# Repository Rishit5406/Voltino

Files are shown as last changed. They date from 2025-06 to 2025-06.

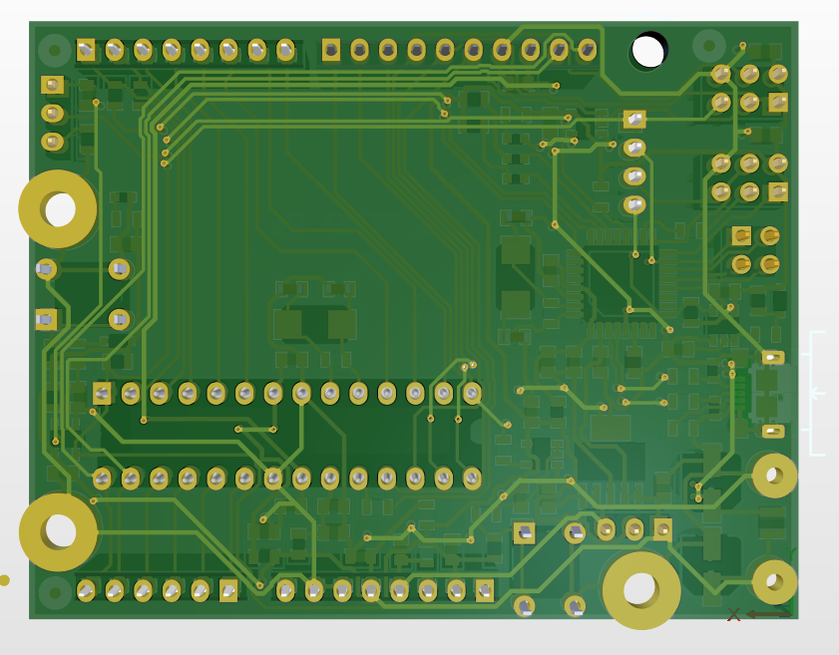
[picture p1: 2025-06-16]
6. Images of PCB/Bottom View.png

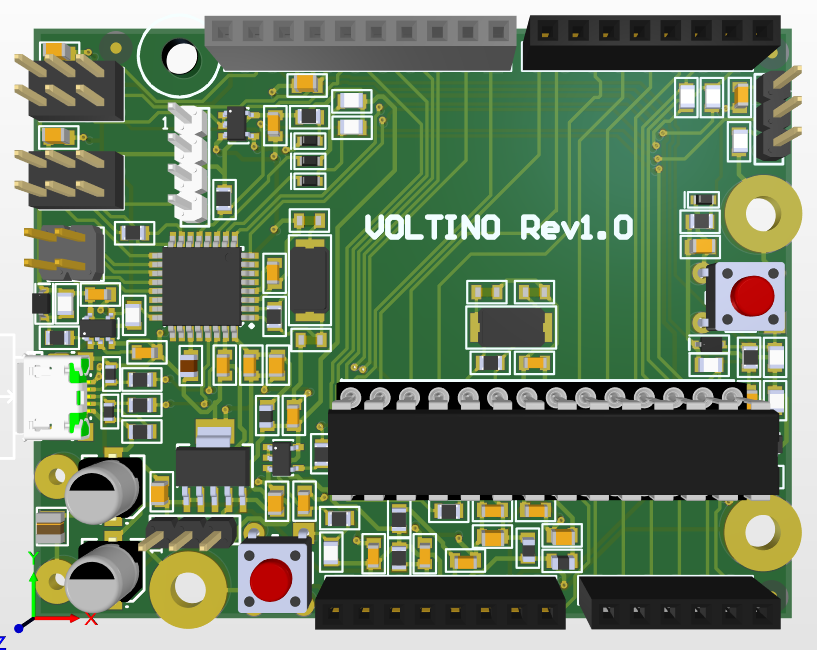
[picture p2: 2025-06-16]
6. Images of PCB/Top View.png

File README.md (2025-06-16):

# VOLTINO – Arduino UNO Rev 3 Inspired Custom Board

**VOLTINO** is a custom-designed, open-source hardware development board inspired by the Arduino™ UNO Rev 3. This project refines the original design based on **Atmel's electrical recommendations** for better current and voltage control, optimized trace routing, and mechanical reliability.

Designed in **Altium Designer**, VOLTINO preserves the standard Arduino UNO pinout while offering a clean layout and professional fabrication-ready output.

---

## 🔧 Features
- Based on **ATmega328P-PU**
- UNO R3 compatible pin headers
- USB and external power supply support
- Enhanced voltage and current control
- Designed for manufacturability and reliability
- STEP file provided for enclosure/CAD integration

---

## 📁 Repository Contents

### 1. `Schematic/`
- Altium schematic PDF of the complete design
- Includes pin labels, power supply routing, and interface mappings

### 2. `PCB Layout/`
- PCB layout PDF exported from Altium
- Layer stack, footprint arrangement, trace routing overview

### 3. `BOM/`
- Bill of Materials (CSV or XLSX)
- Includes part numbers, footprints, and quantity for sourcing

### 4. `STEP File/`
- 3D mechanical export of the PCB in `.STEP` format
- Can be used in Fusion 360, SolidWorks, FreeCAD, etc.

### 5. `Gerber Files/`
- Complete set of fabrication-ready Gerber and NC drill files
- Compliant with JLCPCB, PCBWay, OSH Park, and most fab services

### 6. `Images/`
- High-resolution images:
  - 3D PCB view
  - Annotated schematic
  - Component layout and connections

---

## 🚀 Getting Started

This repository is intended for:
- Makers and hardware engineers looking for an optimized UNO design
- Students building embedded projects
- Fabricators needing ready-to-manufacture open-source boards

To manufacture VOLTINO:
1. Download the Gerber ZIP
2. Upload to your preferred PCB fabricator (e.g., JLCPCB)
3. Refer to the BOM for sourcing components
4. Use the STEP file for enclosure design or 3D simulation

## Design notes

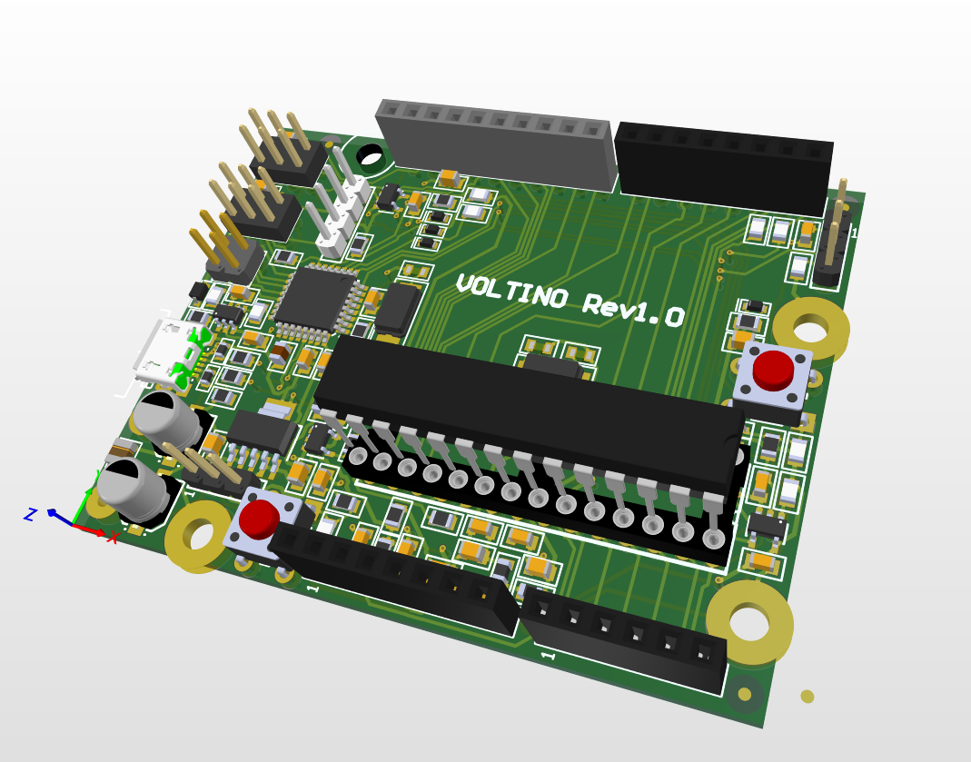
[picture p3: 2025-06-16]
6. Images of PCB/Side View 1.png

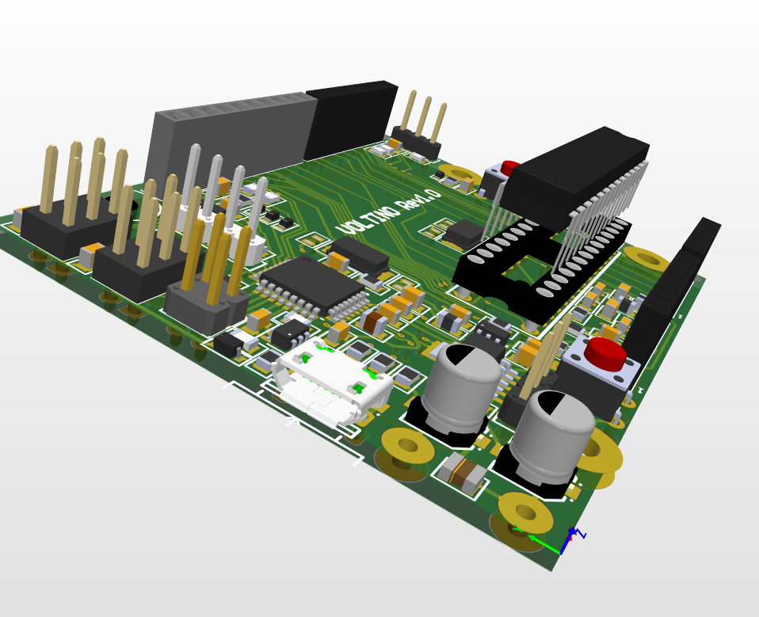
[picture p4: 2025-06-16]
6. Images of PCB/Side View 2.png

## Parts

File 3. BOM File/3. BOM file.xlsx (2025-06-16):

Description | LibRef | Category | Supplier | Supplier Part Number | Manufacturer | Manufacturer Part Number | Quantity | Pricing
Ceramic Capacitor, Multilayer, Ceramic, 50V, 10% +Tol, 10% -Tol, X7R, 15% TC, 0.1uF, Surface Mount, 0805 | C2012X7R1H104K085AA | Ceramic Capacitors | Digikey | 445-7534-1-ND | TDK | C2012X7R1H104K085AA | 17 | 1=0.12, 10=0.069, 100=0.0418, 1000=0.02773 (USD)
Ceramic Capacitor, Multilayer, Ceramic, 16V, 10% +Tol, 10% -Tol, X5R, 15% TC, 10uF, Surface Mount, 0805 | C2012X5R1C106K085AC | Ceramic Capacitors | Digikey | 445-7644-1-ND | TDK | C2012X5R1C106K085AC | 9 | 1=0.21, 10=0.121, 100=0.076, 1000=0.05277 (USD)
Aluminum Electrolytic Capacitor, Polarized, Aluminum (wet), 10V, 20% +Tol, 20% -Tol, 100uF, Surface Mount, 2121 | EEE-1AA101WR | Aluminum Electrolytic Capacitors | Digikey | PCE3867CT-ND | Panasonic | EEE-1AA101WR | 2 | 1=0.36, 10=0.22, 50=0.1606, 100=0.1419, 500=0.10952 (USD)
Ceramic Capacitor, Multilayer, Ceramic, 25V, 10% +Tol, 10% -Tol, X5R, 15% TC, 1uF, Surface Mount, 0805 | C2012X5R1E105K125AA | Ceramic Capacitors | Digikey | 445-1419-1-ND | TDK | C2012X5R1E105K125AA | 1 | 1=0.19, 10=0.106, 100=0.0662, 1000=0.04546 (USD)
Ceramic Capacitor, Multilayer, Ceramic, 50V, 5% +Tol, 5% -Tol, C0G, -/+30ppm/Cel TC, 0.000018uF, Surface Mount, 0805 | C0805C180J5GACTU | Ceramic Capacitors | Digikey | 399-C0805C180J5GACTUCT-ND | KEMET | C0805C180J5GACTU | 4 | 1=0.11, 10=0.06, 100=0.0358, 1000=0.0235 (USD)
LED Uni-Color Yellow 591nm Automotive 2-Pin Chip 0603(1608Metric) T/R | LY L29K-J1K2-26-0-2-R18-Z | LEDs | Digikey | 475-LYL29K-J1K2-26-0-2-R18-ZCT-ND | Osram Opto | LY L29K-J1K2-26-0-2-R18-Z | 3 | 1=0.29, 10=0.195, 100=0.1374, 500=0.111, 1000=0.10226, 2000=0.09482 (USD)
Rectifier Diode, 1 Phase, 1 Element, 0.2A, 30V V(RRM), Silicon | BAT54HT1G | Schottky Diodes | Digikey | BAT54HT1GOSCT-ND | ON Semiconductor / Fairchild | BAT54HT1G | 2 | 1=0.11, 10=0.072, 100=0.0512, 500=0.03702, 1000=0.0324 (USD)
Smartled Green Clear Lc Ali | LGL29K-F2J1-24-0-2-R18-Z | LEDs | Digikey | 475-LGL29K-F2J1-24-0-2-R18-ZCT-ND | Osram | LGL29K-F2J1-24-0-2-R18-Z | 1
Ferrite Chip, 1 Function(s), 2A | MPZ2012S601AT000 | Ferrite Beads and Chips | Digikey | 445-MPZ2012S601AT000CT-ND | TDK | MPZ2012S601AT000 | 3 | 1=0.11, 10=0.075, 25=0.0648, 50=0.0584, 100=0.0522, 250=0.04496, 500=0.03994, 1000=0.0353 (USD)
Fixed Resistor, Metal Glaze/thick Film, 0.125W, 560ohm, 150V, 1% +/-Tol, 100ppm/Cel, Surface Mount, 0805 | RC0805FR-07560RL | Chip SMD Resistors | Digikey | 311-560CRCT-ND | Yageo | RC0805FR-07560RL | 3 | 1=0.1, 10=0.012, 100=0.0112, 1000=0.00714 (USD)
Conn Unshrouded Header HDR 4 POS 2.54mm Solder ST Top Entry Thru-Hole BergStik® Bulk | 67997-204HLF | Headers and Wire Housings | Digikey | 609-3233-ND | Amphenol ICC / FCI | 67997-204HLF | 1 | 1=0.4, 10=0.338, 100=0.2873, 500=0.2564, 1000=0.24415, 5000=0.21793, 10000=0.20753 (USD)
Conn Unshrouded Header HDR 6 POS 2.54mm Solder ST Top Entry Thru-Hole BergStik® Bulk | 67997-106HLF | Headers and Wire Housings | Digikey | 609-3393-ND | Amphenol ICC / FCI | 67997-106HLF | 2 | 1=0.58, 10=0.49, 400=0.37728, 800=0.35925, 1200=0.34911, 5200=0.31479, 10000=0.3006 (USD)
Conn Unshrouded Header HDR 4 POS 2.54mm Solder ST Thru-Hole Bag | 68001-204HLF | Headers and Wire Housings | Digikey | 609-3402-ND | Amphenol ICC / FCI | 68001-204HLF | 1 | 1=0.47, 10=0.401, 100=0.3406, 500=0.30394, 1000=0.28942, 5000=0.25834, 10000=0.24602 (USD)
FCI Right Angle Surface Mount Mount Female USB Connector; 100 V ac; 1.8A | 10118193-0001LF | LDO | Digikey | 609-4616-1-ND | Amphenol ICC / FCI | 10118193-0001LF | 1 | 1=0.43, 10=0.367, 25=0.3436, 50=0.3272, 100=0.3116, 250=0.29204, 500=0.27808 (USD)
Conn Unshrouded Header HDR 3 POS 2.54mm Solder ST Top Entry Thru-Hole BergStik® Automotive Bulk | 68000-103HLF | Headers and Wire Housings | Digikey | 609-3461-ND | Amphenol ICC / FCI | 68000-103HLF | 2 | 1=0.31, 10=0.266, 100=0.2257, 500=0.20142, 1000=0.19179, 5000=0.17119, 10000=0.16302 (USD)
Board Connector, 10 Contact(s), 1 Row(s), Female, Straight, 0.1 inch Pitch, Solder Terminal, Locking, Black Insulator, Socket | M20-7821046 | Headers and Wire Housings | Digikey | 952-1847-ND | Harwin | M20-7821046 | 1 | 1=1.37, 22=1.10409, 110=0.98555, 506=0.88482, 1012=0.84258, 5016=0.75263, 10010=0.71686 (USD)
Board Connector, 8 Contact(s), 1 Row(s), Female, Straight, 0.1 inch Pitch, Solder Terminal, Locking, Black Insulator, Socket | M20-7820842 | Headers and Wire Housings | Digikey | 952-1823-ND | Harwin | M20-7820842 | 2 | 1=1.27, 27=1.0063, 108=0.91231, 513=0.81725, 1026=0.77824, 5022=0.69577, 10017=0.66272 (USD)
Board Connector, 6 Contact(s), 1 Row(s), Female, Straight, 0.1 inch Pitch, Solder Terminal, Locking, Black Insulator, Socket | M20-7820646 | Headers and Wire Housings | Digikey | 952-1809-ND | Harwin | M20-7820646 | 1 | 1=1.11, 36=0.86417, 108=0.79954, 504=0.7171, 1008=0.68287, 5004=0.60989, 10008=0.58081 (USD)
General Purpose Inductor, 2.2uH, 20%, 1 Element, Metal Composite-Core, SMD | CIGT252008LM2R2MNE | Fixed Inductors | Digikey | 1276-6925-1-ND | Samsung | CIGT252008LM2R2MNE | 1 | 1=0.18, 10=0.148, 100=0.1221, 1000=0.1004 (USD)
Shunts/Jumper Connector | QPC02SXGN-RC | Connectors | Digikey | S9337-ND | Sullins | QPC02SXGN-RC | 3 | 1=0.1, 10=0.025, 25=0.0236, 50=0.0224, 100=0.0213, 250=0.02, 500=0.01904, 2000=0.01726, 4000=0.01644 (USD)
Fixed Resistor, Metal Glaze/thick Film, 0.125W, 100000ohm, 150V, 1% +/-Tol, 100ppm/Cel, Surface Mount, 0805 | RC0805FR-07100KL | Chip SMD Resistors | Digikey | 311-100KCRCT-ND | Yageo | RC0805FR-07100KL | 1 | 1=0.1, 10=0.014, 100=0.0112, 1000=0.00918, 5000=0.00408, 10000=0.00306 (USD)
Fixed Resistor, Metal Glaze/thick Film, 0.125W, 1000ohm, 150V, 1% +/-Tol, 100ppm/Cel, Surface Mount, 0805 | RC0805FR-071KL | Chip SMD Resistors | Digikey | 311-1.00KCRCT-ND | Yageo | RC0805FR-071KL | 5 | 1=0.1, 10=0.012, 100=0.0112, 1000=0.00714, 2500=0.00686 (USD)
Fixed Resistor, Metal Glaze/thick Film, 0.125W, 10000ohm, 150V, 1% +/-Tol, 100ppm/Cel, Surface Mount, 0805 | RC0805FR-0710KL | Chip SMD Resistors | Digikey | 311-10.0KCRDKR-ND | Yageo | RC0805FR-0710KL | 7 | 1=0.14, 10=0.016, 100=0.0122, 1000=0.00918 (USD)
Fixed Resistor, Metal Glaze/thick Film, 0.125W, 22ohm, 150V, 1% +/-Tol, 100ppm/Cel, Surface Mount, 0805 | RC0805FR-0722RL | Chip SMD Resistors | Digikey | 311-22.0CRCT-ND | Yageo | RC0805FR-0722RL | 7 | 1=0.1, 10=0.012, 100=0.0112, 1000=0.00918, 2500=0.00686, 5000=0.00408 (USD)
Metal Glaze/thick Film, 0.125W, 0ohm, Surface Mount, 0805 | RC0805JR-070RL | Chip SMD Resistors | Digikey | 311-0.0ARCT-ND | Yageo | RC0805JR-070RL | 3 | 1=0.1, 10=0.015, 25=0.0128, 50=0.011, 100=0.0097, 250=0.00812, 500=0.00716, 1000=0.00633 (USD)
Fixed Resistor, Metal Glaze/thick Film, 0.125W, 1000000ohm, 150V, 1% +/-Tol, 100ppm/Cel, Surface Mount, 0805 | RC0805FR-071ML | Chip SMD Resistors | Digikey | 311-1.00MCRCT-ND | Yageo | RC0805FR-071ML | 2 | 1=0.1, 10=0.014, 100=0.0112, 1000=0.00918, 5000=0.00408, 10000=0.00357, 15000=0.00306 (USD)
IC Socket, DIP28, 28 Contact(s) | 4828-3004-CP | Connectors | Digikey | 3M5480-ND | 3M | 4828-3004-CP | 1 | 1=0.96, 14=0.79786, 28=0.75929, 56=0.72304, 112=0.68848, 252=0.65016, 504=0.61911, 1008=0.58954, 2506=0.55285 (USD)
Keypad Switch, 1 Switches, SPST, Momentary-tactile, 0.05A, 24VDC, 2.06N, 4 PCB Hole Cnt, Solder Terminal, Through Hole-straight | 1825910-6 | Pushbutton Switches | Digikey | 450-1650-ND | TE Connectivity Alcoswitch | 1825910-6 | 2 | 1=0.13, 10=0.118, 25=0.1112, 100=0.1001, 250=0.093, 750=0.08485, 1500=0.08009, 3000=0.07565, 5250=0.07234 (USD)
RISC Microcontroller, 8-Bit, FLASH, AVR RISC CPU, 20MHz, CMOS, PDIP28 | ATMEGA328P-PU | Microcontrollers | Digikey | ATMEGA328P-PU-ND | Microchip | ATMEGA328P-PU | 2 | 1=2.89, 25=2.65, 100=2.39 (USD)
AND Gate, AHCT/VHCT/VT Series, 1-Func, 2-Input, CMOS, PDSO5 | 74AHC1G09W5-7 | Logic Gates | Digikey | 74AHC1G09W5-7DICT-ND | Diodes | 74AHC1G09W5-7 | 4 | 1=0.21, 10=0.142, 25=0.1252, 100=0.1068, 250=0.098, 500=0.09272, 1000=0.08836 (USD)
Microcontroller, 8-Bit, FLASH, AVR RISC CPU, 16MHz, CMOS, PQFP32 | ATMEGA16U2-AUR | Microcontrollers | Digikey | ATMEGA16U2-AURCT-ND | Microchip | ATMEGA16U2-AUR | 1 | 1=3.34, 25=3.06, 100=2.75 (USD)
Fixed Positive LDO Regulator, 3.3V, 0.55V Dropout, BIPolar, PDSO6 | TL1963A-33DCQR | Voltage Regulators - Linear | Digikey | 296-24534-1-ND | Texas Instruments | TL1963A-33DCQR | 1 | 1=3.3, 10=2.479, 25=2.2736, 100=2.0475, 250=1.93968, 500=1.87468, 1000=1.82118 (USD)
Crystal 16MHz ±20ppm (Tol) ±30ppm (Stability) 18pF FUND 50Ohm 2-Pin Mini-CSMD T/R | ABM7-16.000MHZ-D2Y-T | Crystals | Digikey | 535-9840-1-ND | Abracon | ABM7-16.000MHZ-D2Y-T | 2 | 1=0.66, 10=0.573, 50=0.5196, 100=0.4867, 500=0.45152 (USD)
Varistor, 5V, Surface Mount | CG0603MLC-05E | Varistors | Digikey | CG0603MLC-05ECT-ND | Bourns | CG0603MLC-05E | 2 | 1=0.25, 10=0.169, 25=0.15, 100=0.1283, 250=0.11804, 500=0.11182, 1000=0.10671, 2500=0.10132 (USD)

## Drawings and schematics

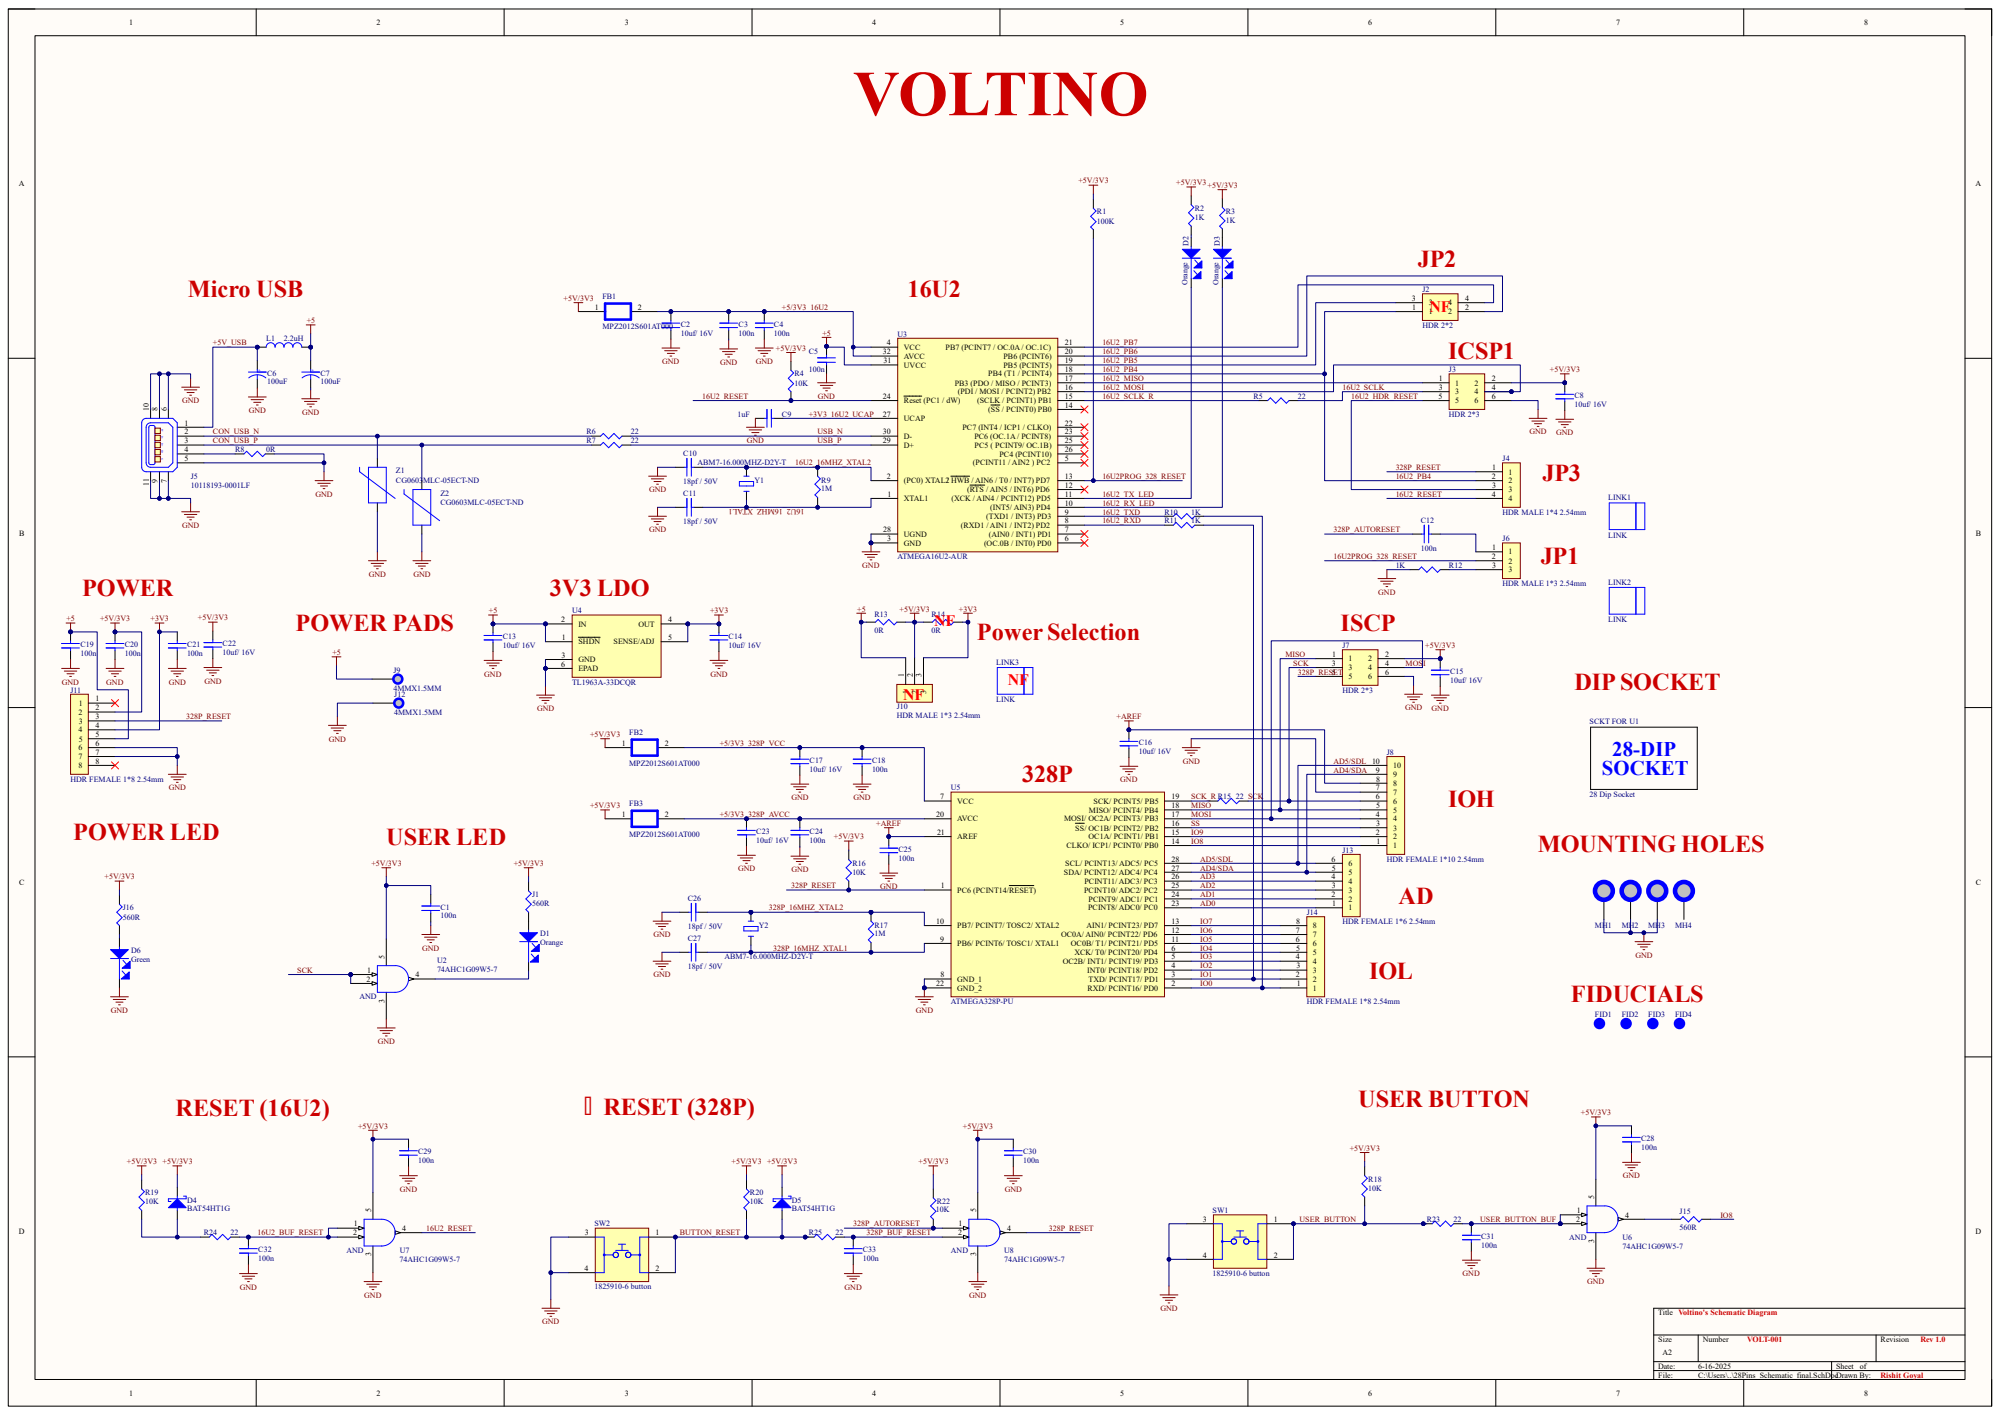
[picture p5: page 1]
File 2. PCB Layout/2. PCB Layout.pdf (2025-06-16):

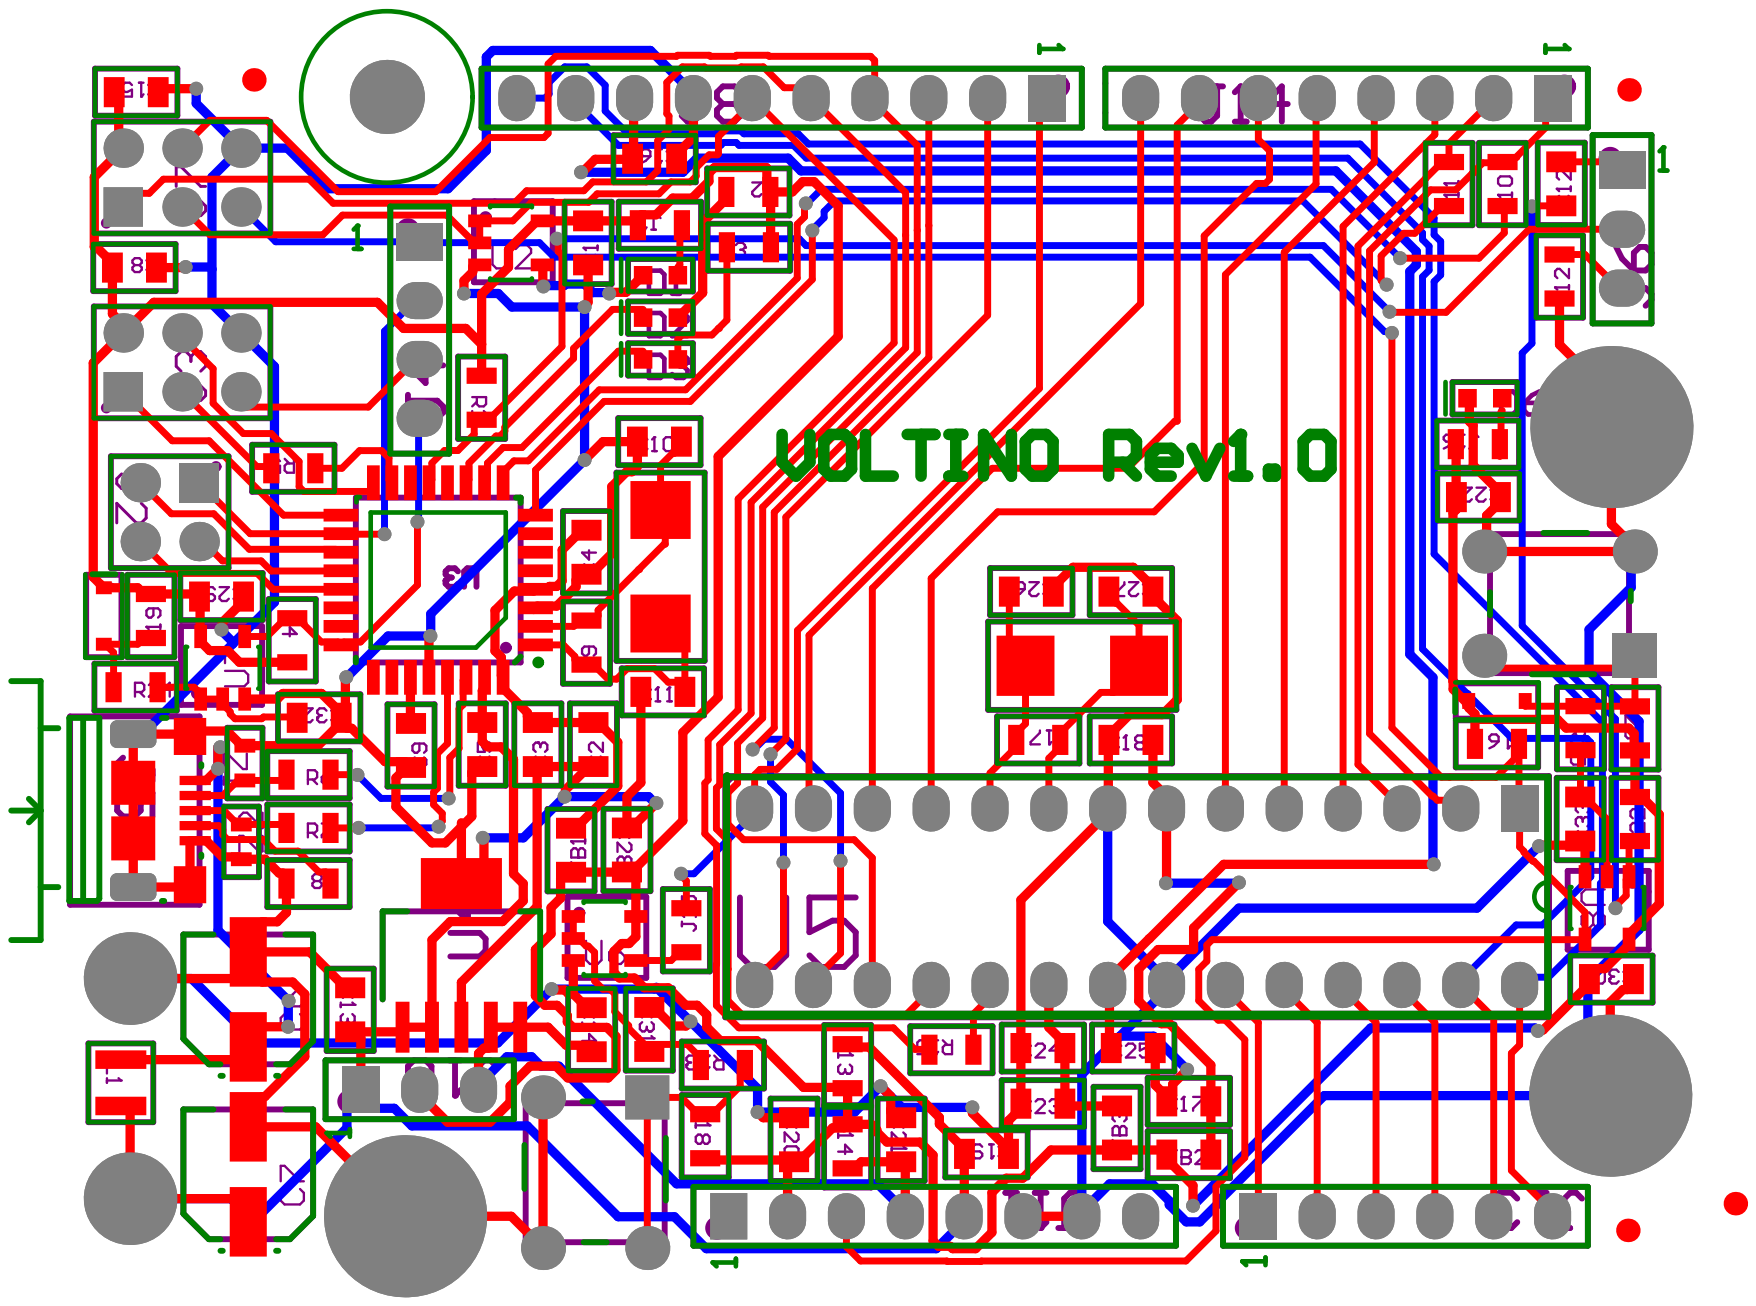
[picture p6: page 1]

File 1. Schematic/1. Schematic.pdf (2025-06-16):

NF

Micro USB | 16U2
